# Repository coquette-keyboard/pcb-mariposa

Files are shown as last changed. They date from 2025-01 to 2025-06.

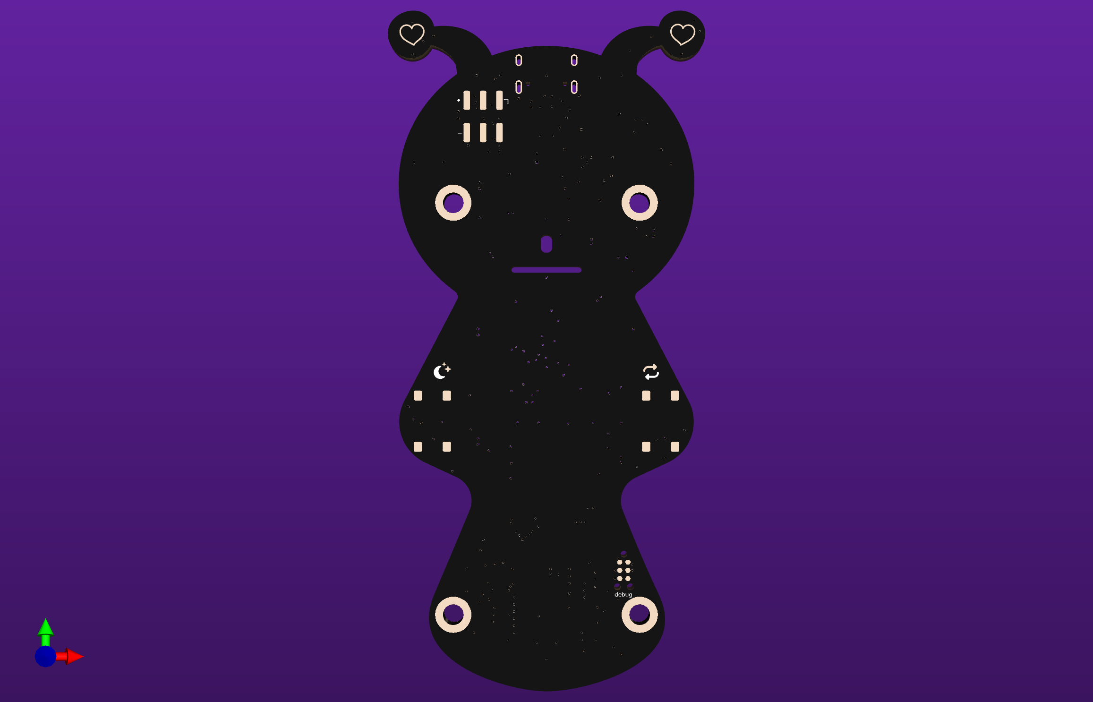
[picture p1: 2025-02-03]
mariposa-front.png

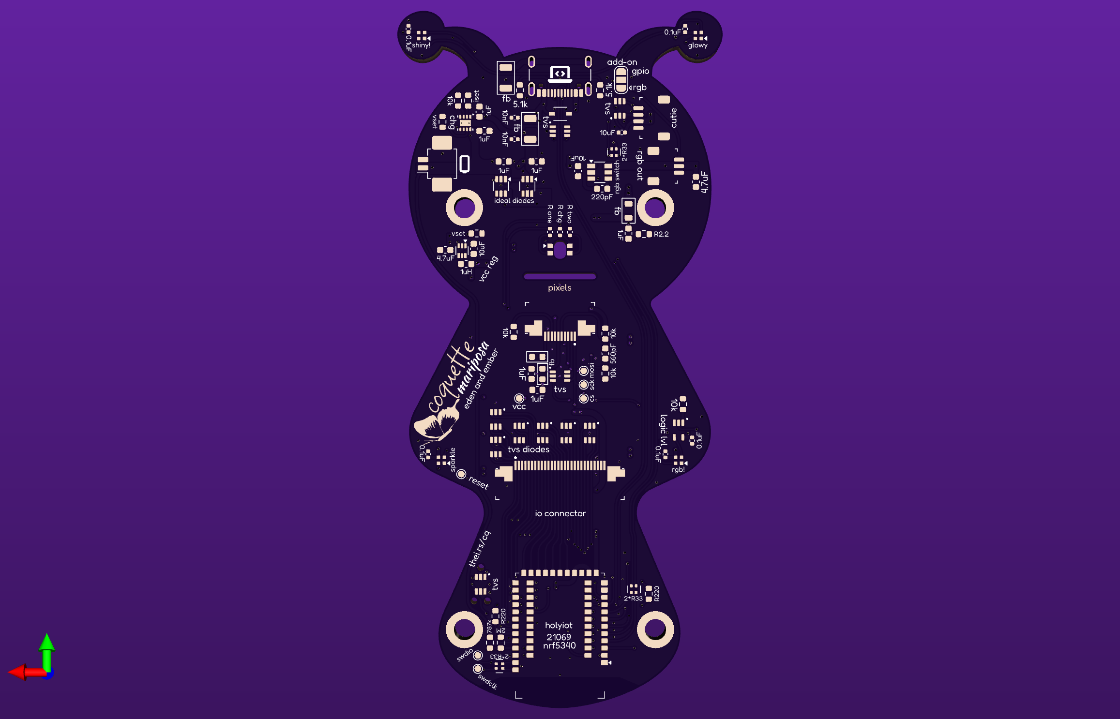
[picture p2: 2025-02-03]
mariposa-back.png

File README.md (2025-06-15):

# mariposa-pcb

mariposa is the microcontroller board for the coquette keyboard. note that this project, this board, the associated keyboard shields, and all firmware, is untested and provided with no guarantees or liability for failures, safety hazards, reguatory compliance, and/or injuries and/or losses in any form.

## bill of materials

- Raytac MTBT53-1M nRF5340 module - this is the microcontroller that runs the keyboard
- TI TPS62842DGRR DCDC converter - chosen for its 60nA quiescent current, this powers it
- TI BQ25170DSGR lipoly charger - charges the battery
- Sharp memory-in-pixel LCD that fits on top and has the 10-pin connection that matches the pinout, a few sizes should work
- 2 TI LM66100DCK ideal diode ICs - used to implement ORing between the battery and USB
- 1 TI TPS22917DBV - high side load switch for addressable RGB power. the quiescent on those things is soooooo high relative to the keeb you'll probably want to turn off power completely on battery
- 1 TI SN74LV1T125DCK - converts addressable RGB logic to input voltage for LEDs
- 1 32.768KHz 9pF load cap 3215 2-pin SMD crystal - external LFXO to reduce power use compared to internal oscillator
- 1 TI TSD05C TVS diode, protects USB VBUS input from ESD events
- 4 TI TPD4E1U06 TVS diode arrays, protects exposed data pins + USB data lines from ESD events
- 1 390pF NP0 ceramic capacitor, used to set ARGB power switch slew rate
- 1 560pF NP0 ceramic capacitor, the sharp memory display wants it, idk why
- 3 10nF 0603 ceramic capacitors, two for USB power RC filter, one for battery voltage sampling
- 8 0.1uF 0603 ceramic capacitors, used for decoupling
- 9 1uF 0603 ceramic capacitors, used for decoupling
- 3 4.7uF 1206 ceramic capacitors, used for decoupling
- 2 10uF 0805 ceramic capacitors - decopling, but more power!
- 1 R2.2 0805 thick film resistor, VBUS input surge protection
- 1 0603 1% resistor for DCDC vset, 0R - 1.8V, 1.74k - 2.2V, 21.5k - 3V, 28.7k - 3.1V, 38.3k - 3.2V, 52.3k - 3.3V – use 52.3k if you want accessories that use power to work, but 2.2V is probably the most efficient if no screen, no add-ons, no display, and no UV underglow on גחלילית או פרפר 
- 1 0603 1% resistor for charger VSET, 27k for 4.2V, 36k for 4.1V which will prolong battery longevity at the expense of runtime but this thing should last ages anyway. up to you.
- 1 2xR27 2x0603 convex resistor array - impedance matching USB data pair
- 1 0603 1% resistor for charger ISET, formula is 300/resistor in kohm = charge current in mA. i'm using 1.8k for 167mA charge current. most batteries it is dangerous to exceed 1C (charge current in mA = battery capacity in mAh)
- 2 R620 0805 thick film resistors, one for current limiting LED data output, one for current limiting status LED
- 1 2x whatever 2x0603 convex resistor array - marked as 2.2k as good value, but hard package to find so use whatever, it's just current limiting a couple button inputs as a safety measure
- 2 5.1k 0603 resistors, identify USB-C device
- 1 7.5M 0805 1% or better resistor - one leg of battery level voltage divider
- 1 15M 1206 1% or better resistor - the other leg of battery level voltage divider
- 1 2x10k or 2x4.7k (or really do some math) 2x0402 convex resistor array - optional, i2c pullups, value depends on speed
- 2 10k*4 4x0603 resistor arrays - a few uses, mostly pulling up or down pins
- 1 2xR33 2x0603 convex resistor array - terminating i2c and SWD
- 2 10uH 0603 - nRF internal DCDC
- 1 2.2uH 1008/2520 inductor - DCDC
- 2 1206 ferrites - 60-120 Ohm or so should be good, USB power and shell filtering
- 2 0805 ferrites - 240 Ohm or so is fine and better for noise, much less current here, LCD analog power filtering
- 2 G-Switch GT-TC041B-H036-L1N - side mount tactile switches for power and reset buttons
- 1 of the most common top-mount SMD USB 2.0 USB-C connector there is. take your pick, seriously, they almost all will fit but the GCT USB4105 is the one the footprint's actually meant for 
- 1 2-pin horizontal PicoBlade connector - battery input
- 1 28-pin 0.5mm pitch FFC SMD connector - output to keyboard, be sure the mounting legs will fit
- 1 10-pin 0.5mm pitch FPC SMD connector - output to LCD, be sure the mounting legs will fit
- 1 JST_SH_SM03B-SRSS-TB_1x03 or similar - ARGB output
- 1 JST_SH_SM04B-SRSS-TB_1x04 or similar - Adafruit Stemma QT-like i2c output
- 1 JST_SH_SM08B-SRSS-TB_1x08 or similar - Pimoroni SP/CE-like SPI and PWM output
- 1 shitty add-on SMD connector - for Hackaday v1.69bis shitty add ons
- 6 SK6805-EC14 ARGB LEDs - picked for the 0.25mA quiescent, still even at 0% brightness the 1.5mA total will drain a 250mAh battery in under a day. be sure you use the load switch wisely
- 1 0805 LED - for a status light. have fun!

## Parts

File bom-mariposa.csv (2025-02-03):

Id | Designator | Footprint | Quantity | Designation | Supplier and ref
1 | J9 | PinSocket_2x03_P2.54mm_Vertical_SMD | 1 | Conn_02x03_Odd_Even
2 | SW3,SW1 | SW_SPST_PTS645 | 2 | SW_Push
3 | C7,C10,C3,C47,C2,C46,C6 | C_0603_1608Metric | 7 | 1uF
4 | D14,D4,D13,D3,D11,D7,D12,D10,D2,D8 | TPD4E1U06 | 10 | TPD4E1U06
5 | C8,C45 | C_0603_1608Metric | 2 | 10 uF
6 | TP4,TP7,TP6,TP8,TP2,TP1,TP3 | TestPoint_Pad_D1.0mm | 7 | TestPoint
7 | R11 | R_0603_1608Metric | 1 | 249k
8 | J8 | JST_SH_SM04B-SRSS-TB_1x04-1MP_P1.00mm_Horizontal | 1 | Conn_01x04_MountingPin
9 | U4 | TPS22917DBV | 1 | TPS22917DBV
10 | D18,D16,D15,D17 | SK6805-EC14 | 4 | SK6805-EC14
11 | R7 | R_0603_1608Metric | 1 | 1.5k
12 | R19,R20 | R_0402_1005Metric | 2 | 1.67k
13 | LED1 | E6CC1205RGBC3UDA | 1 | LED_Generic_RGB_RABG
14 | C13 | C_0603_1608Metric | 1 | 4.7uF
15 | C4,C5,C12 | C_0402_1005Metric | 3 | 10nF
16 | R15 | R_0603_1608Metric | 1 | 27k
17 | FB3,FB4 | Ferrite_0603_1608Metric | 2 | 240 Ohm
18 | U3,U6 | LM66100DCK | 2 | LM66100DCK
19 | R16,R1 | R_0603_1608Metric | 2 | R220
20 | D9 | TSD05C | 1 | TI TSD05C
21 | R12,R18,R5,R13,R6,R8 | R_0603_1608Metric | 6 | 10k
22 | U1 | holyiot_21069_nRF5340 | 1 | ~
23 | U7 | SN74LV1T125DCK | 1 | SN74LV1T125DCK
24 | C1 | C_0603_1608Metric | 1 | 560pF
25 | C14,C16,C17,C15,C11 | C_0402_1005Metric | 5 | 0.1uF
26 | J4 | USB_C_Receptacle_GCT_USB4105-xx-A_16P_TopMnt_Horizontal | 1 | USB_C_Receptacle_USB2.0_16P
27 | BT1 | Molex_PicoBlade_53261-0271_1x02-1MP_P1.25mm_Horizontal | 1 | Battery
28 | RN2,RN3,RN1 | R_Array_Convex_2x0402 | 3 | 2*R33
29 | R2 | R_0402_1005Metric | 1 | 5k
30 | J6 | AMPHENOL_SFV10R-1STE1HLF | 1 | Conn_01x10_MountingPin
31 | R9 | R_0603_1608Metric | 1 | 787k
32 | C44 | C_0603_1608Metric | 1 | 4.7 uF
33 | L1 | L_0603_1608Metric | 1 | 1 uH
34 | R3,R4 | R_0603_1608Metric | 2 | 5.1k
35 | C9 | C_0603_1608Metric | 1 | 220pF
36 | FB5 | Ferrite_0805_2012Metric | 1 | 120 Ohm
37 | R10 | R_0603_1608Metric | 1 | 2M
38 | FB1,FB2 | Ferrite_1206_3216Metric | 2 | 120 Ohm
39 | U2 | DSG0008A | 1 | BQ25170DSGR
40 | U5 | TPS628438DRL | 1 | TPS628438DRL
41 | J2 | JST_SH_SM03B-SRSS-TB_1x03-1MP_P1.00mm_Horizontal | 1 | Conn_01x03_MountingPin
42 | J1 | AMPHENOL_SFV28R-1STE1HLF | 1 | Conn_01x28_MountingPin
43 | R17 | R_0603_1608Metric | 1 | R2.2

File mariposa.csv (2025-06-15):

Id | Designator | Footprint | Quantity | Designation | Supplier and ref
1 | C7,C8,C18,C19,C3,C47,C2,C46,C6 | C_0603_1608Metric | 9 | 1uF
2 | C49,C44,C48 | C_1206_3216Metric | 3 | 4.7uF
3 | R11 | R_0603_1608Metric | 1 | 28.7k
4 | J8 | JST_SH_SM04B-SRSS-TB_1x04-1MP_P1.00mm_Horizontal | 1 | Conn_01x04_MountingPin
5 | U4 | TPS22917DBV | 1 | TPS22917DBV
6 | D20,D16,D15,D19,D18,D17 | SK6805-EC14 | 6 | SK6805-EC14
7 | L2,L3 | L_0603_1608Metric | 2 | 10uH
8 | RN5 | R_Array_Convex_2x0603 | 1 | 2*R27
9 | R7 | R_0603_1608Metric | 1 | 1.8k
10 | D13,D12,D14,D10 | TPD4E1U06 | 4 | TPD4E1U06
11 | C45,C53 | C_0805_2012Metric | 2 | 10uF
12 | C4,C5,C10 | C_0603_1608Metric | 3 | 10nF
13 | R15 | R_0603_1608Metric | 1 | 36k
14 | FB3,FB4 | Ferrite_0805_2012Metric | 2 | 240 Ohm
15 | C21,C14,C20,C16,C17,C15,C12,C11 | C_0603_1608Metric | 8 | 0.1uF
16 | U3,U6 | LM66100DCK | 2 | LM66100DCK
17 | D9 | TSD05C | 1 | TI TSD05C
18 | RN9 | R_Array_Convex_2x0603 | 1 | 2*2.2k
19 | U7 | SN74LV1T125DCK | 1 | SN74LV1T125DCK
20 | RN7,RN6 | R_Array_Convex_4x0603 | 2 | 10k*4
21 | C1 | C_0603_1608Metric | 1 | 560pF
22 | J4 | USB_C_Receptacle_GCT_USB4105-xx-A_16P_TopMnt_Horizontal | 1 | USB_C_Receptacle_USB2.0_16P
23 | R13,R8 | R_0603_1608Metric | 2 | R620
24 | BT1 | Molex_PicoBlade_53261-0271_1x02-1MP_P1.25mm_Horizontal | 1 | Battery
25 | R21 | R_0805_2012Metric | 1 | R2.2
26 | U1 | HVSSOP-8-1EP_3x3mm_P0.65mm_EP1.57x1.89mm_ThermalVias | 1 | TPS62842DGRR
27 | J6 | Hirose_FH12-10S-0.5SH_1x10-1MP_P0.50mm_Horizontal | 1 | Conn_01x10_MountingPin
28 | R9 | R_0805_2012Metric | 1 | 7.5M
29 | RN4 | R_Array_Convex_2x0402 | 1 | 2*10k
30 | SW3,SW1 | G-Switch GT-TC041B-H036-L1N | 2 | SW_Push
31 | MDBT1 | MDBT53 | 1 | ~
32 | L1 | L_1008_2520Metric | 1 | 2.2uH
33 | R3,R4 | R_0603_1608Metric | 2 | 5.1k
34 | C9 | C_0603_1608Metric | 1 | 390pF
35 | R10 | R_1206_3216Metric | 1 | 15M
36 | FB1,FB2 | Ferrite_1206_3216Metric | 2 | 120 Ohm
37 | U2 | DSG0008A | 1 | BQ25170DSGR
38 | Y1 | Crystal_SMD_3215-2Pin_3.2x1.5mm | 1 | CFPX-217 32.768KHz
39 | D1 | LED_0603_1608Metric | 1 | LED
40 | J5 | JST_SH_SM08B-SRSS-TB_1x08-1MP_P1.00mm_Horizontal | 1 | Conn_01x08_MountingPin
41 | J2 | JST_SH_SM03B-SRSS-TB_1x03-1MP_P1.00mm_Horizontal | 1 | Conn_01x03_MountingPin
42 | RN8 | R_Array_Convex_4x0603 | 1 | R33*4
43 | J1 | Hirose_FH12-28S-0.5SH_1x28-1MP_P0.50mm_Horizontal | 1 | Conn_01x28_MountingPin
44 | J9 | PinSocket_2x03_P2.54mm_Vertical_SMD | 1 | Conn_02x03_Odd_Even

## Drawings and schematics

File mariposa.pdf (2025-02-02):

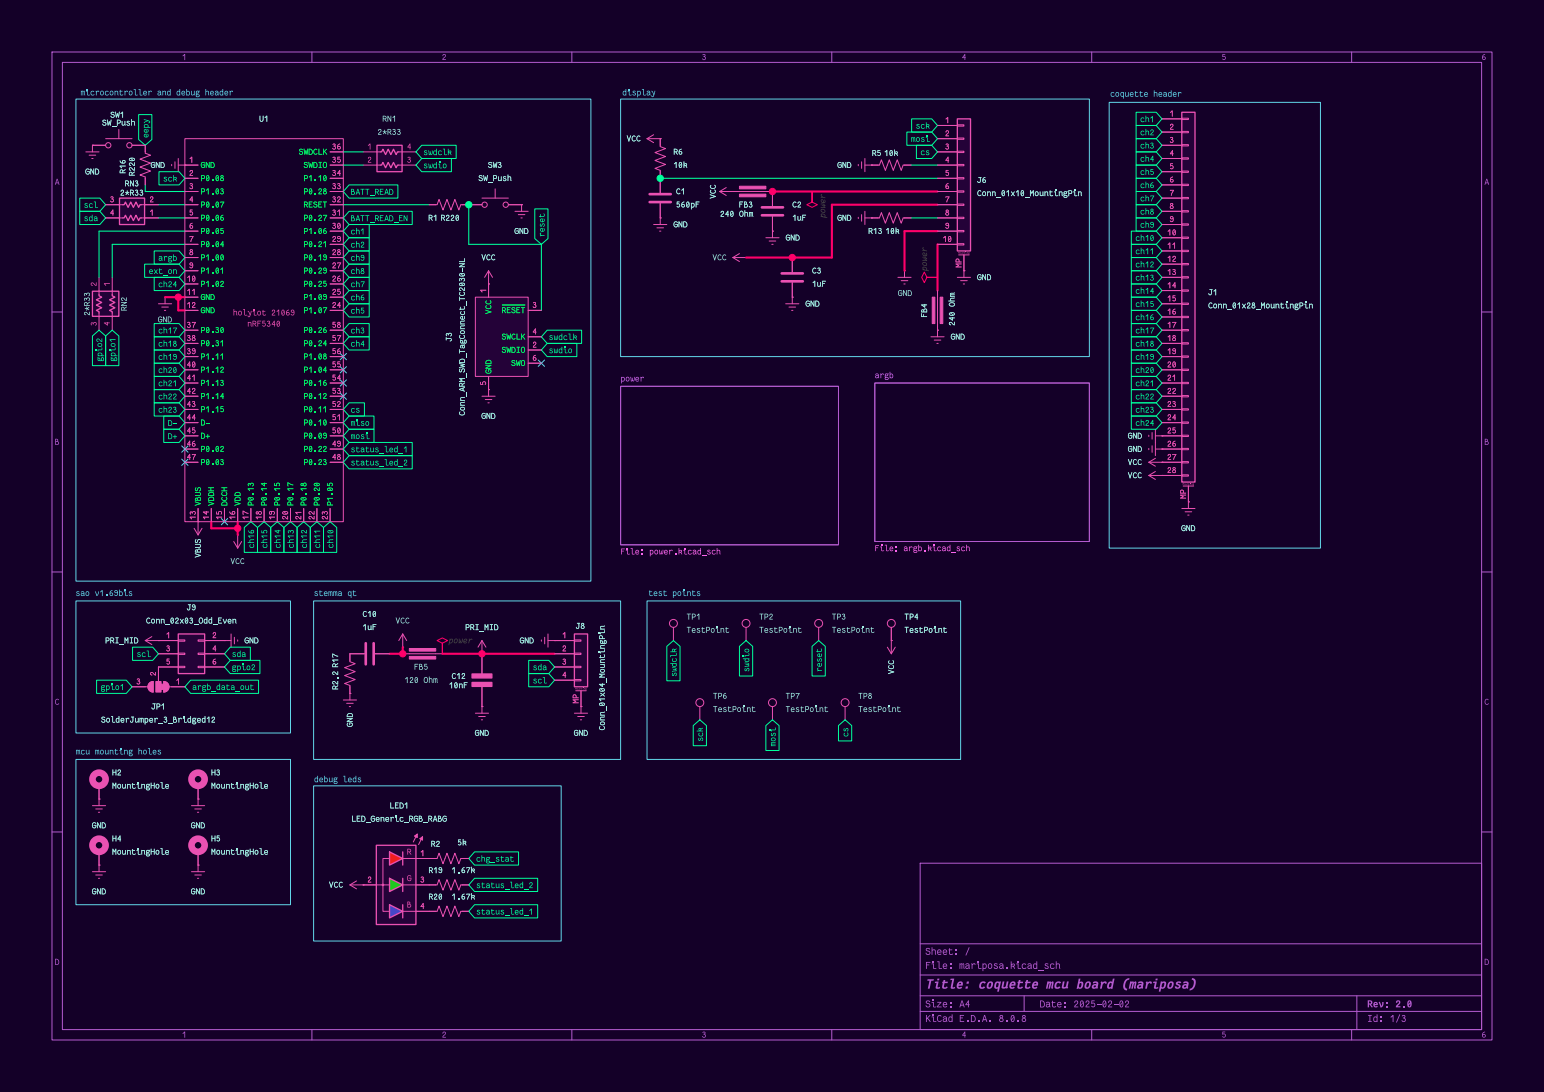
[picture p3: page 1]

5 SWO6 U1 GND 1 P1.02 10 GND 11 GND 12 VBUS 13 VDDH 14 DCCH 15 VDD 16 P0.13 17 P0.14 18 P0.15 19 P0.08 2 P0.17 20 P0.18 21 P0.20 22 P1.05 23 P1.07 24 P1.09 25 P0.25 26 P0.29 27 P0.19 28 P0.21 29 P1.03 3 P1.06 30 P0.27 31 RESET32 P0.28 33 P1.10 34 SWDIO35 SWDCLK36 P0.30 37 P0.31 38 P1.11 39 P0.07 4 P1.12 40 P1.13 41 P1.14 42 P1.15 43 D- 44 D+ 45 P0.02 46 P0.03 47 P0.23 48 P0.22 49 P0.06 5 P0.09 50 P0.10 51 P0.11 52 P0.12 53 P0.16 54 P1.04 55 P1.08 56 P0.24 57 P0.26 58 P0.05 6 P0.04 7 P1.00 8 P1.01 9 GND

test points mcu mounting holes

H3 MountingHole H5 MountingHole GND GND GND

Id: 1/3 Title: coquette mcuboard (mariposa) File: mariposa.kicad_sch Sheet: /

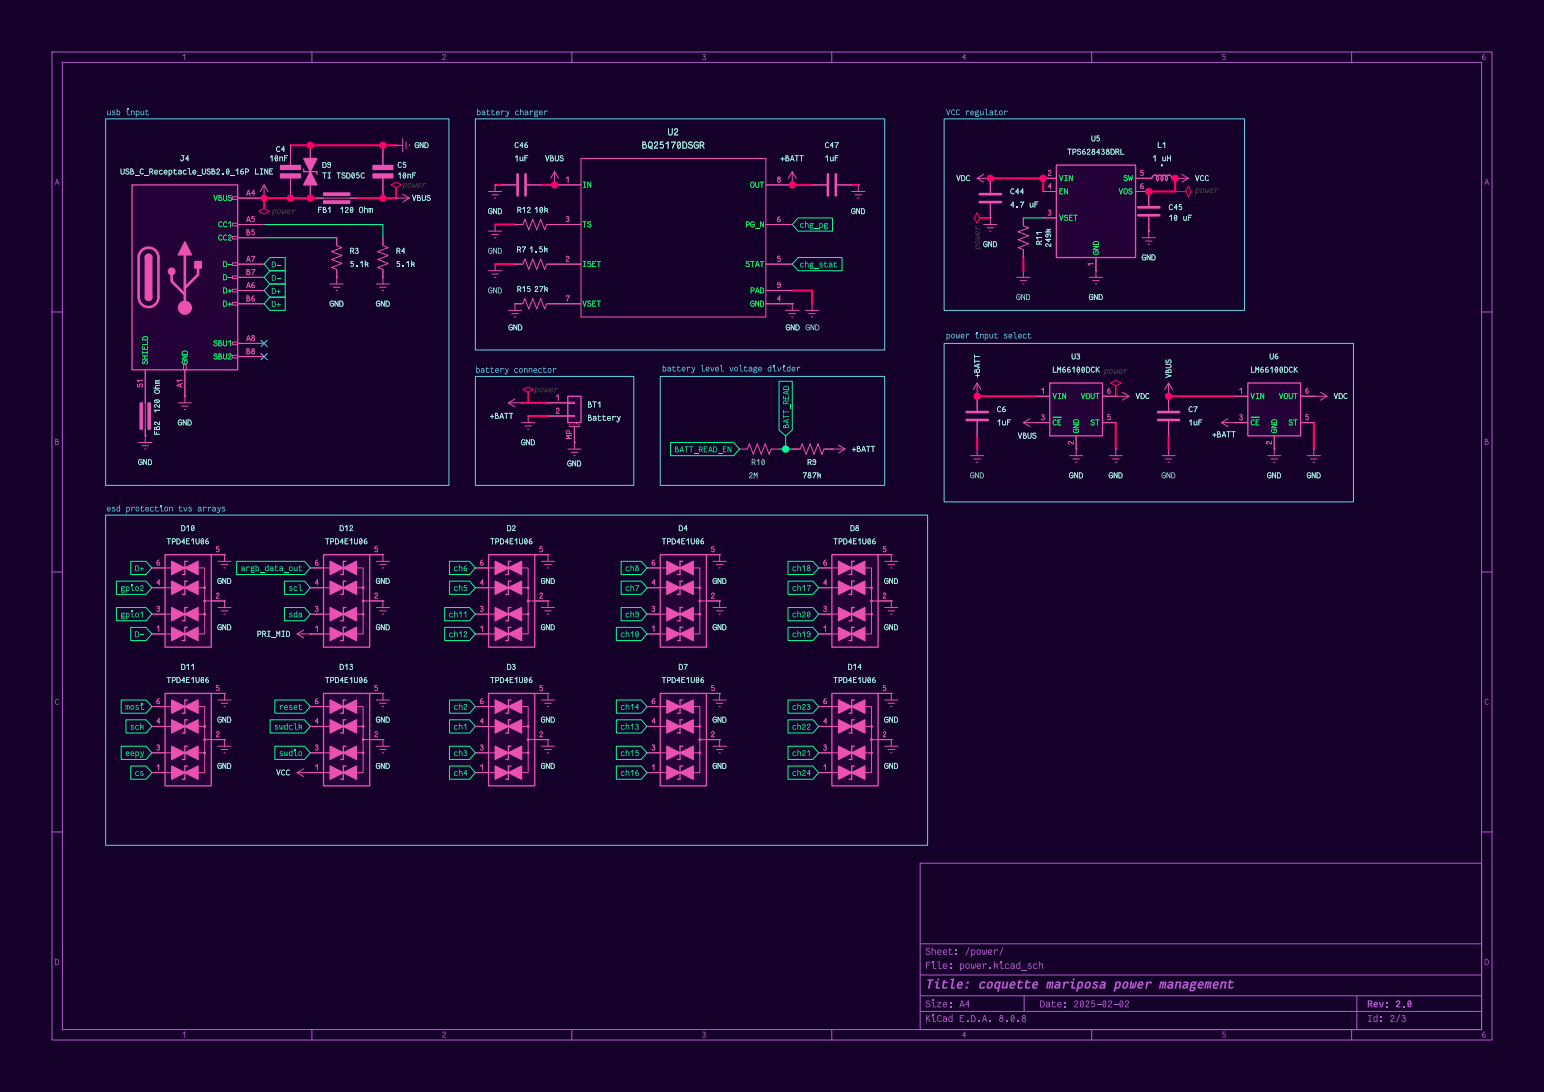
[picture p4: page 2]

1 VIN 2 VSET 3 EN 4 SW 5 VOS 6 U5 TPS628438DRL L1
10 uF VDC

1 VIN 2 VSET 3 EN 4 SW 5 VOS 6

2 ~{CE} 3 ST 5 VOUT6 GND GND

esd protection tvs arrays

Id: 2/3 Title: coquette mariposa power management File: power.kicad_sch Sheet: /power/ 1

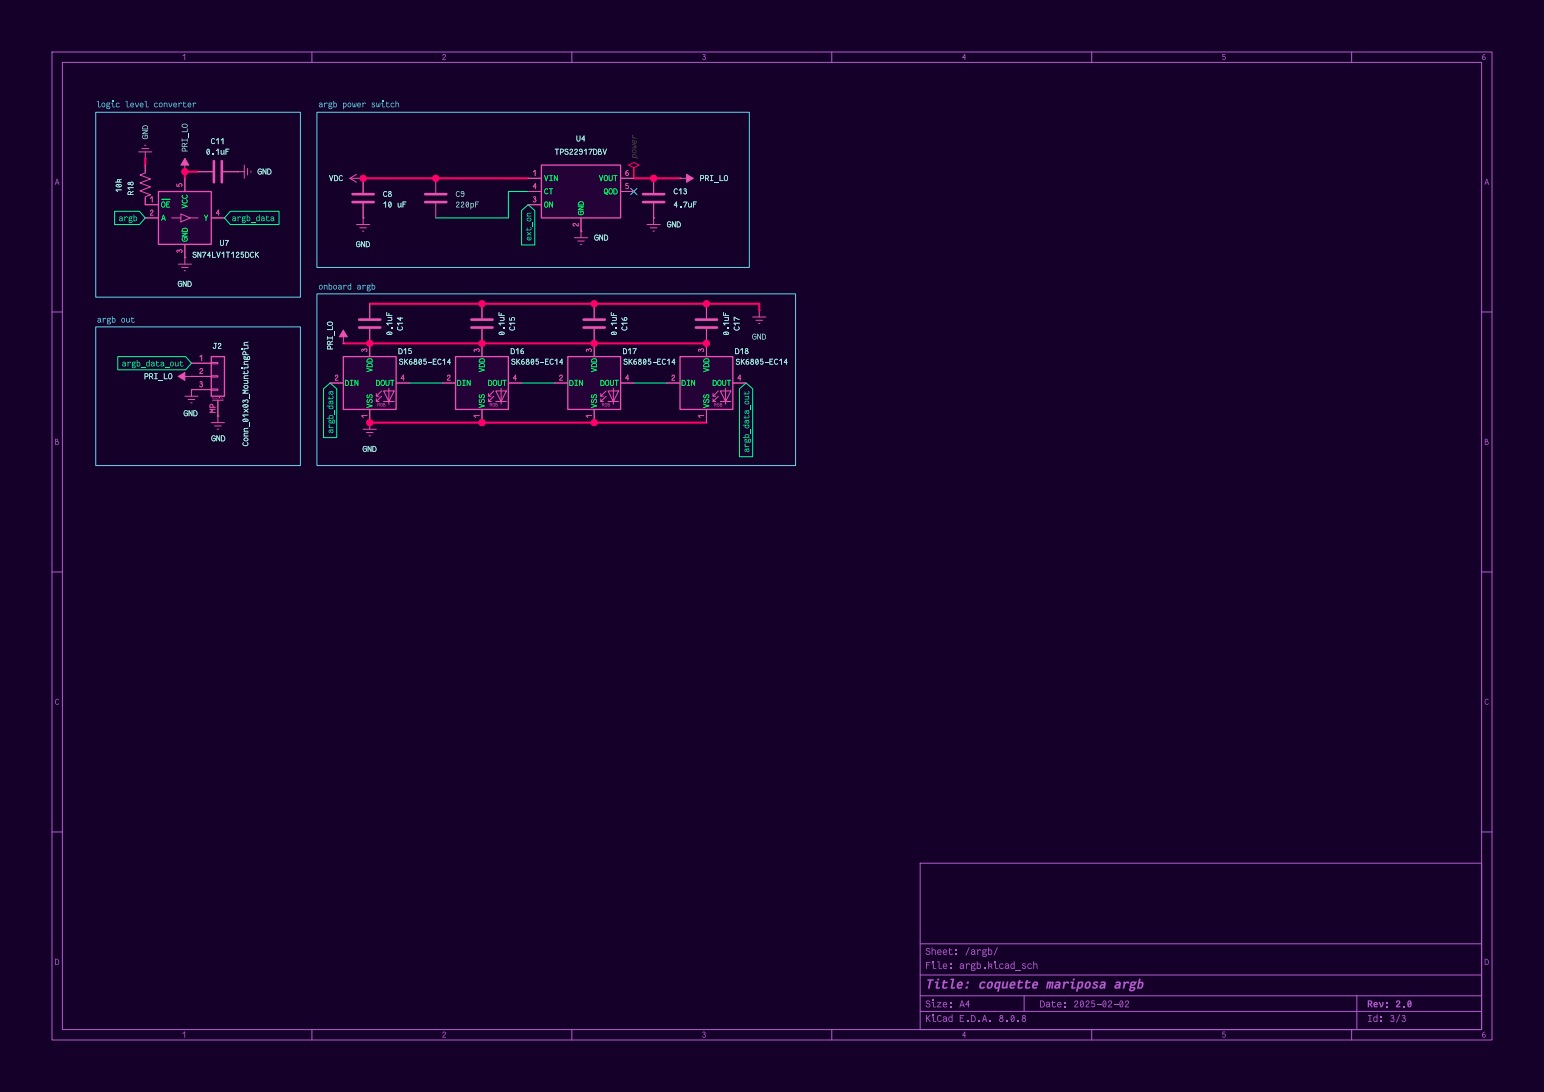
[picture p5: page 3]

File: argb.kicad_sch Sheet: /argb/
Id: 3/3 Title: coquette mariposa argb

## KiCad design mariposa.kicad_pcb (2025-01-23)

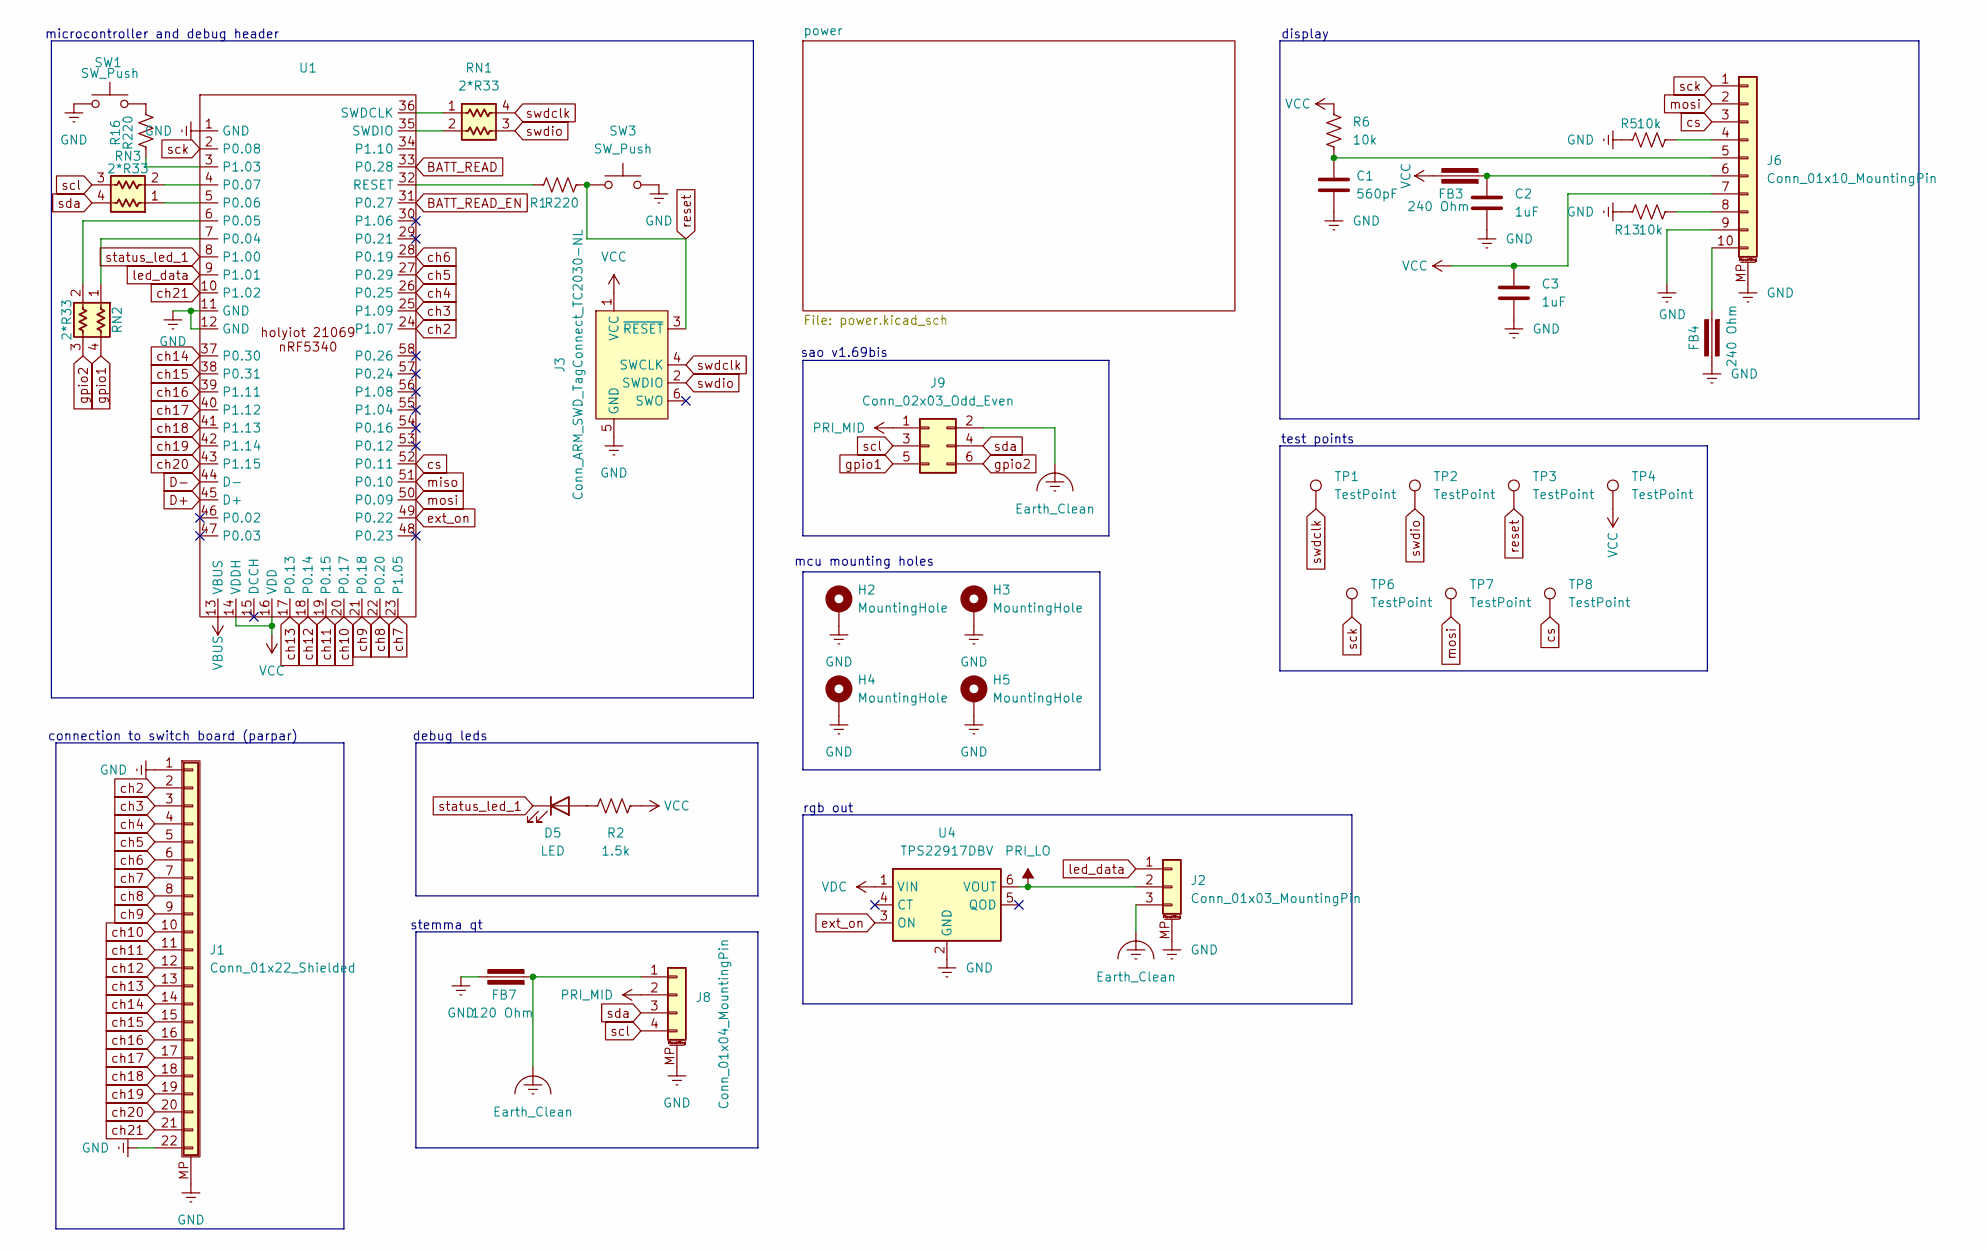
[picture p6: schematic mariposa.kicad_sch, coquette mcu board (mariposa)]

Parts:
C1: 560pF; C_0603_1608Metric
C2, C3: 1uF; C_0603_1608Metric
D5: LED; LED 1206 reverse mount rectangle
FB3, FB4: 240 Ohm; Ferrite_0603_1608Metric
FB7: 120 Ohm; Ferrite_0805_2012Metric
H2, H3, H4, H5: MountingHole; MountingHole_3.2mm_M3_DIN965_Pad
J1: Conn_01x22_Shielded; Hirose_FH12-22S-0.5SH_1x22-1MP_P0.50mm_Horizontal
J2: Conn_01x03_MountingPin; JST_SH_SM03B-SRSS-TB_1x03-1MP_P1.00mm_Horizontal
J3: Conn_ARM_SWD_TagConnect_TC2030-NL; Tag-Connect_TC2030-IDC-NL_2x03_P1.27mm_Vertical
J6: Conn_01x10_MountingPin; Hirose_FH12-10S-0.5SH_1x10-1MP_P0.50mm_Horizontal
J8: Conn_01x04_MountingPin; JST_SH_SM04B-SRSS-TB_1x04-1MP_P1.00mm_Horizontal
J9: Conn_02x03_Odd_Even; PinSocket_2x03_P2.54mm_Vertical_SMD
R1, R16: R220; R_0603_1608Metric
R2: 1.5k; R_0603_1608Metric
R5, R6, R13: 10k; R_0603_1608Metric
RN1, RN2, RN3: 2*R33; R_Array_Convex_2x0402
SW1, SW3: SW_Push; SW_SPST_PTS645
TP1, TP2, TP3, TP4, TP6, TP7, TP8: TestPoint; TestPoint_Pad_D1.0mm
U1: holyiot_21069_nRF5340
U4: TPS22917DBV; SOT-23-6

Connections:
BATT_READ: U1.33 (P0.28); also elsewhere on the board
BATT_READ_EN: U1.31 (P0.27); also elsewhere on the board
D+: U1.45 (D+); also elsewhere on the board
D-: U1.44 (D-); also elsewhere on the board
Earth_Clean: FB7.1, J2.3, J8.1, J9.2
GND: C1.2, C2.2, C3.2, FB4.2, FB7.2, H2.1, H3.1, H4.1, H5.1, J1.1, J1.22, J1.MP, J2.MP (MountPin), J3.5 (GND), J6.9, J6.MP (MountPin), J8.MP (MountPin), R5.1, R13.1, SW1.1, SW3.2, U1.1 (GND), U1.11 (GND), U1.12 (GND), U4.2 (GND); also elsewhere on the board
unnamed: D5.2 (A), R2.1
unnamed: J6.4, R5.2
unnamed: C1.1, J6.5, R6.1
unnamed: C2.1, FB3.1, J6.6
unnamed: J6.8, R13.2
unnamed: FB4.1, J6.10
unnamed: R16.1, SW1.2
unnamed: RN1.1 (R1.1), U1.36 (SWDCLK)
unnamed: RN1.2 (R2.1), U1.35 (SWDIO)
unnamed: RN2.1 (R1.1), U1.7 (P0.04)
unnamed: RN2.2 (R2.1), U1.6 (P0.05)
unnamed: RN3.1 (R1.1), U1.5 (P0.06)
unnamed: RN3.2 (R2.1), U1.4 (P0.07)
unnamed: R16.2, U1.3 (P1.03)
unnamed: R1.1, U1.32 (RESET)
PRI_LO: J2.2, U4.6 (VOUT)
PRI_MID: J8.2, J9.1; also elsewhere on the board
VBUS: U1.13 (VBUS); also elsewhere on the board
VCC: C3.1, FB3.2, J3.1 (VCC), J6.7, R2.2, R6.2, TP4.1, U1.14 (VDDH), U1.16 (VDD); also elsewhere on the board
VDC: U4.1 (VIN); also elsewhere on the board
ch2: J1.2, U1.24 (P1.07)
ch3: J1.3, U1.25 (P1.09)
ch4: J1.4, U1.26 (P0.25)
ch5: J1.5, U1.27 (P0.29)
ch6: J1.6, U1.28 (P0.19)
ch7: J1.7, U1.23 (P1.05)
ch8: J1.8, U1.22 (P0.20)
ch9: J1.9, U1.21 (P0.18)
ch10: J1.10, U1.20 (P0.17)
ch11: J1.11, U1.19 (P0.15)
ch12: J1.12, U1.18 (P0.14)
ch13: J1.13, U1.17 (P0.13)
ch14: J1.14, U1.37 (P0.30)
ch15: J1.15, U1.38 (P0.31)
ch16: J1.16, U1.39 (P1.11)
ch17: J1.17, U1.40 (P1.12)
ch18: J1.18, U1.41 (P1.13)
ch19: J1.19, U1.42 (P1.14)
ch20: J1.20, U1.43 (P1.15)
ch21: J1.21, U1.10 (P1.02)
cs: J6.3, TP8.1, U1.52 (P0.11); also elsewhere on the board
ext_on: U1.49 (P0.22), U4.3 (ON)
gpio1: J9.5, RN2.4 (R1.2); also elsewhere on the board
gpio2: J9.6, RN2.3 (R2.2); also elsewhere on the board
led_data: J2.1, U1.9 (P1.01); also elsewhere on the board
miso: U1.51 (P0.10)
mosi: J6.2, TP7.1, U1.50 (P0.09); also elsewhere on the board
reset: J3.3 (~RESET), R1.2, SW3.1, TP3.1; also elsewhere on the board
sck: J6.1, TP6.1, U1.2 (P0.08); also elsewhere on the board
scl: J8.4, J9.3, RN3.3 (R2.2); also elsewhere on the board
sda: J8.3, J9.4, RN3.4 (R1.2); also elsewhere on the board
status_led_1: D5.1 (K), U1.8 (P1.00); also elsewhere on the board
swdclk: J3.4 (SWCLK), RN1.4 (R1.2), TP1.1; also elsewhere on the board
swdio: J3.2 (SWDIO), RN1.3 (R2.2), TP2.1; also elsewhere on the board

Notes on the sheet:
stemma qt
rgb out
test points
display
microcontroller and debug header
connection to switch board (parpar)
mcu mounting holes
debug leds
sao v1.69bis

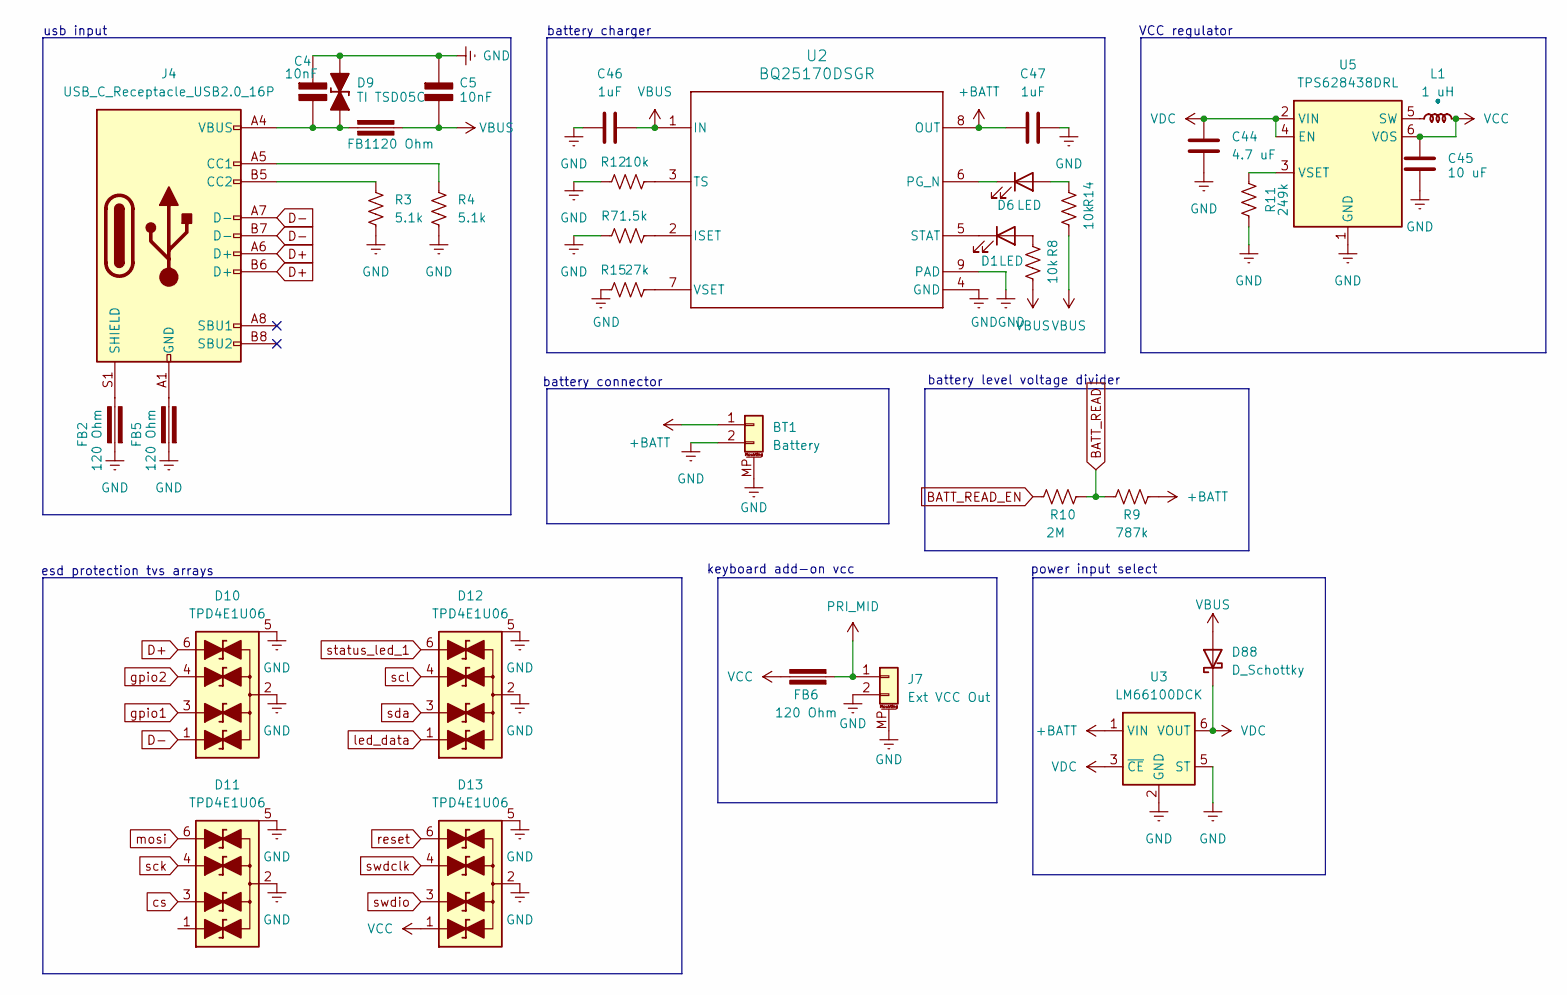
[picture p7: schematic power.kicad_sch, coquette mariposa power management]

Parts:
BT1: Battery; JST_GH_SM02B-GHS-TB_1x02-1MP_P1.25mm_Horizontal
C4, C5: 10nF; C_0603_1608Metric; Rating V
C44: 4.7 uF; C_0603_1608Metric
C45: 10 uF; C_0603_1608Metric
C46, C47: 1uF; C_0603_1608Metric
D1, D6: LED; LED 1206 reverse mount rectangle
D9: TI TSD05C; D_SOD-323_TVS
D10, D11, D12, D13: TPD4E1U06; SOT-363_SC-70-6
D88: D_Schottky; D_SOD-123F
FB1, FB2, FB5, FB6: 120 Ohm; Ferrite_0805_2012Metric
J4: USB_C_Receptacle_USB2.0_16P; USB_C_Receptacle_GCT_USB4105-xx-A_16P_TopMnt_Horizontal
J7: Ext VCC Out; JST_SUR_SM02B-SURS-TF_1x02-1MP_P0.80mm_Horizontal
L1: 1 uH; L_0603_1608Metric
R3, R4: 5.1k; R_0603_1608Metric
R7: 1.5k; R_0603_1608Metric
R8, R12, R14: 10k; R_0603_1608Metric
R9: 787k; R_0603_1608Metric
R10: 2M; R_0603_1608Metric
R11: 249k; R_0603_1608Metric
R15: 27k; R_0603_1608Metric
U2: BQ25170DSGR; DSG0008A
U3: LM66100DCK; SOT-363_SC-70-6
U5: TPS628438DRL; SOT-563

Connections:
+BATT: BT1.1, C47.1, R9.1, U2.8 (OUT), U3.1 (VIN)
BATT_READ: R9.2, R10.1; also elsewhere on the board
BATT_READ_EN: R10.2; also elsewhere on the board
D+: D10.6 (L4), J4.A6 (D+), J4.B6 (D+); also elsewhere on the board
D-: D10.1 (L1), J4.A7 (D-), J4.B7 (D-); also elsewhere on the board
GND: BT1.2, BT1.MP (MountPin), C4.1 (+), C5.1 (+), C44.2, C45.2, C46.1, C47.2, D9.1 (K), D10.2 (VN), D10.5 (NC), D11.2 (VN), D11.5 (NC), D12.2 (VN), D12.5 (NC), D13.2 (VN), D13.5 (NC), FB2.1, FB5.1, J7.2, J7.MP (MountPin), R3.2, R4.2, R7.2, R11.2, R12.2, R15.2, U2.4 (GND), U2.9 (PAD), U3.2 (GND), U3.5 (ST), U5.1 (GND); also elsewhere on the board
unnamed: C4.2 (-), D9.2 (A), FB1.1, J4.A4 (VBUS), J4.A9 (VBUS), J4.B4 (VBUS), J4.B9 (VBUS)
unnamed: D1.2 (A), R8.2
unnamed: D1.1 (K), U2.5 (STAT)
unnamed: D6.2 (A), R14.2
unnamed: D6.1 (K), U2.6 (PG_N)
unnamed: FB5.2, J4.A1 (GND), J4.A12 (GND), J4.B1 (GND), J4.B12 (GND)
unnamed: J4.A5 (CC1), R4.1
unnamed: J4.B5 (CC2), R3.1
unnamed: FB2.2, J4.S1 (SHIELD)
unnamed: L1.1 (+), U5.5 (SW)
unnamed: R7.1, U2.2 (ISET)
unnamed: R12.1, U2.3 (TS)
unnamed: R15.1, U2.7 (VSET)
unnamed: R11.1, U5.3 (VSET)
PRI_MID: FB6.1, J7.1; also elsewhere on the board
VBUS: C5.2 (-), C46.2, D88.2 (A), FB1.2, R8.1, R14.1, U2.1 (IN); also elsewhere on the board
VCC: C45.1, D13.1 (L1), FB6.2, L1.2 (-), U5.6 (VOS); also elsewhere on the board
VDC: C44.1, D88.1 (K), U3.3 (~CE), U3.6 (VOUT), U5.2 (VIN), U5.4 (EN); also elsewhere on the board
cs: D11.3 (L2); also elsewhere on the board
gpio1: D10.3 (L2); also elsewhere on the board
gpio2: D10.4 (L3); also elsewhere on the board
led_data: D12.1 (L1); also elsewhere on the board
mosi: D11.6 (L4); also elsewhere on the board
reset: D13.6 (L4); also elsewhere on the board
sck: D11.4 (L3); also elsewhere on the board
scl: D12.4 (L3); also elsewhere on the board
sda: D12.3 (L2); also elsewhere on the board
status_led_1: D12.6 (L4); also elsewhere on the board
swdclk: D13.4 (L3); also elsewhere on the board
swdio: D13.3 (L2); also elsewhere on the board

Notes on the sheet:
esd protection tvs arrays
battery connector
battery charger
power input select
usb input
battery level voltage divider
keyboard add-on vcc
VCC regulator

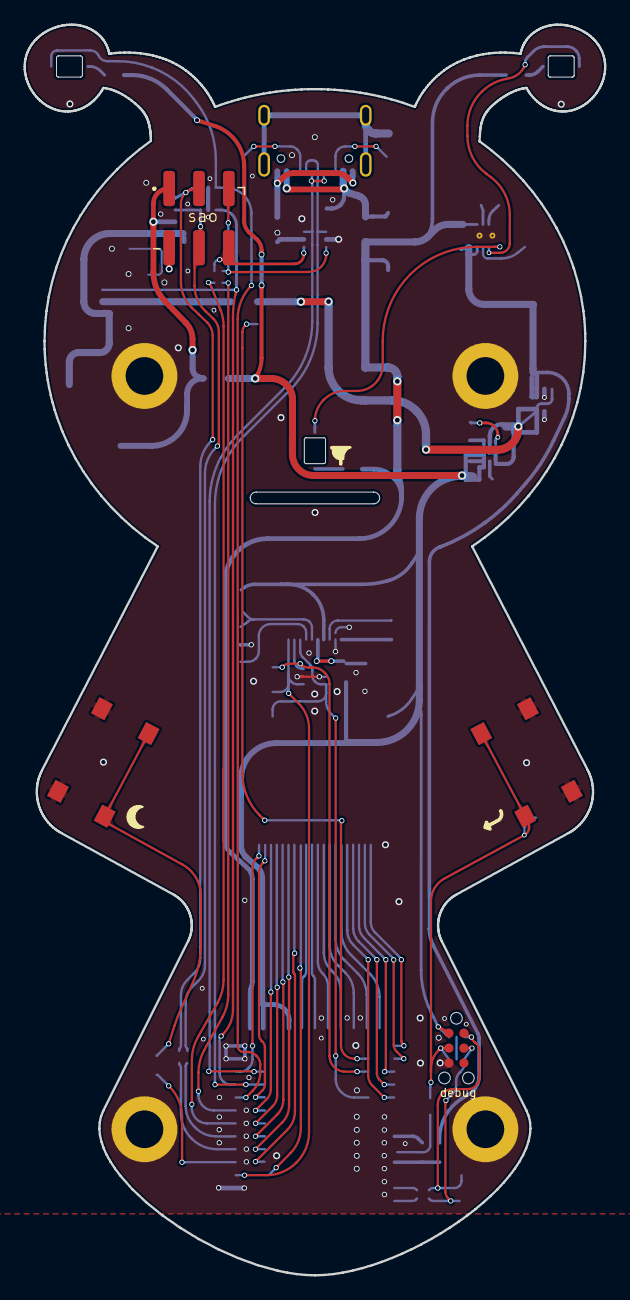
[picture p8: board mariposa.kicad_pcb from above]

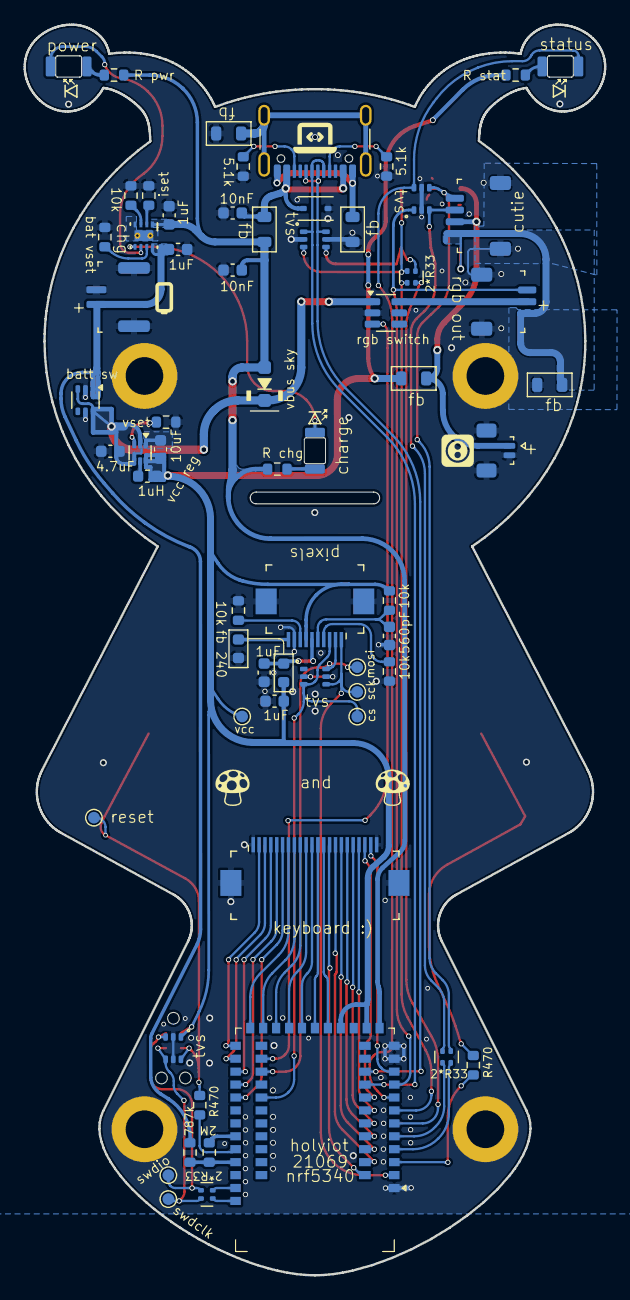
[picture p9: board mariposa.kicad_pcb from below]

Board: 2 copper layers, 49.4 x 106.4 mm, 72 parts (64 on the bottom side), 74 nets.

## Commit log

2025-01-08 mariposa v2 RC1
    [charger_input.kicad_sch, input and battery.kicad_sch, key matrix.kicad_sch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]
2025-01-16 mariposa v2 RC2
    [mariposa.kicad_pcb, mariposa.kicad_sch, power.kicad_sch]
2025-01-19 mariposa v2 RC3
    [mariposa.kicad_pcb, mariposa.kicad_sch, power.kicad_sch]
2025-01-19 parpar mariposa mk2 rc6
    [mariposa.kicad_pcb]
2025-01-19 remove old files
    [charger_input.kicad_sch, input and battery.kicad_sch, key matrix.kicad_sch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]
2025-01-19 parpar mariposa mk2 rc7
    [mariposa.kicad_pcb]
2025-01-19 parpar mariposa mk2 rc8
    [mariposa.kicad_pcb]
2025-01-19 coquette mariposa mk2 final?
    [mariposa-B_Cu.gbr, mariposa-B_Mask.gbr, mariposa-B_Paste.gbr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]
2025-01-19 update bom
    [bom-mariposa.csv]
2025-01-20 another resistor value to a real-world existing part
    [bom-mariposa.csv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]
2025-01-21 actually production version, for real?
    [bom-mariposa.csv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]
2025-01-21 the final, actual, mk2 production files
    [mariposa-B_Cu.gbr, mariposa-B_Mask.gbr, mariposa-B_Paste.gbr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]
2025-01-23 the final, actual, mk2 production files for real
    [bom-mariposa.csv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]
2025-02-01 mariposa v2 pre
    [argb.kicad_sch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]
2025-02-02 update date
    [argb.kicad_sch, mariposa.kicad_sch, power.kicad_sch]
2025-02-02 title page 3 of schematic
    [argb.kicad_sch, mariposa.kicad_sch]
2025-02-03 final to order
    [argb.kicad_sch, bom-mariposa.csv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]
2025-03-26 v3 efforts
    [addons.kicad_sch, argb.kicad_sch, mariposa.csv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]
2025-04-01 more rounding
    [argb.kicad_sch, mariposa.kicad_pcb, mariposa.kicad_sch]
2025-04-04 nearing the end
    [addons.kicad_sch, argb.kicad_sch, mariposa.kicad_pcb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]
2025-04-19 new dcdc
    [mariposa.kicad_pcb, mariposa.kicad_sch, power.kicad_sch]
2025-04-19 new dcdc rerouting
    [mariposa.kicad_pcb]
2025-05-11 maybe order?
    [mariposa-B_Cu.gbl, mariposa-B_Mask.gbs, mariposa-B_Paste.gbp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]
2025-05-11 jlc order
    [mariposa-B_Cu.gbl, mariposa-B_Mask.gbs, mariposa-B_Paste.gbp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]
2025-06-04 fix crystal routing clearance
    [argb.kicad_sch, power.kicad_sch]
2025-06-07 improve routing and silkscreen
2025-06-11 minor tweaks
    [mariposa.kicad_sch, power.kicad_sch]
2025-06-15 updated readme, tweaked routing
    [mariposa.csv, power.kicad_sch]
